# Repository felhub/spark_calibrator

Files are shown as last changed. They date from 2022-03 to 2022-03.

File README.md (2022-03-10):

# spark_calibrator
## Be carefull! Igntion coils can step up the voltage up to 1:100, wich means on the secondary side there can be voltages up to 40kV!
Over serial communication controlled spark generator using an arduino as digital controller and a car ignition coil as step up transformer.  
A 3D modell of the full assembly and spark gab, as well as all 3d printed parts will be added soon.

## Schematics (without Arduino)
A MOSFET is used to switch the coil. To avoid voltage spikes on the direct switching action, C2 is used to buffer the spike.  
To limit the overall voltage spike on the primary side, the TVS-diode D2 is used to limit to 440V.  

Switching and digital side are isolated via an optocoupler

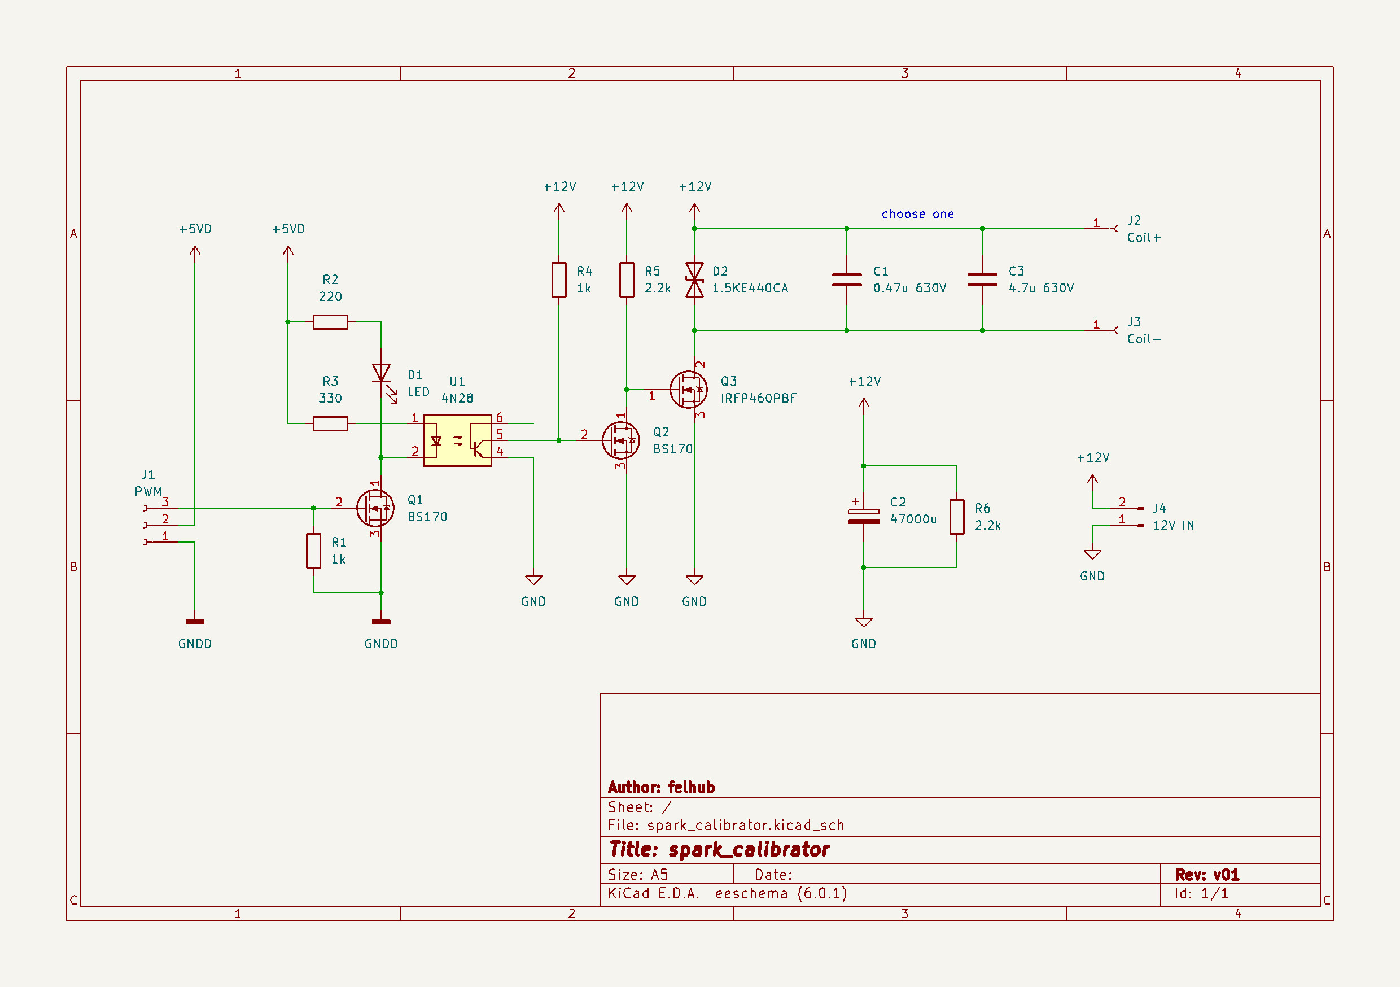
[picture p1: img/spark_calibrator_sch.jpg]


## Simulation

In blue one can see the input pwm signal, triggering the charge of the coil, seen in the current over the coil in red. After voltage to the coil is cut of, the magnetic field collapses with a huge voltage spike in green. The spike is limited by the TVS-diode to 440V, this can be seen as clipping on the green signal.

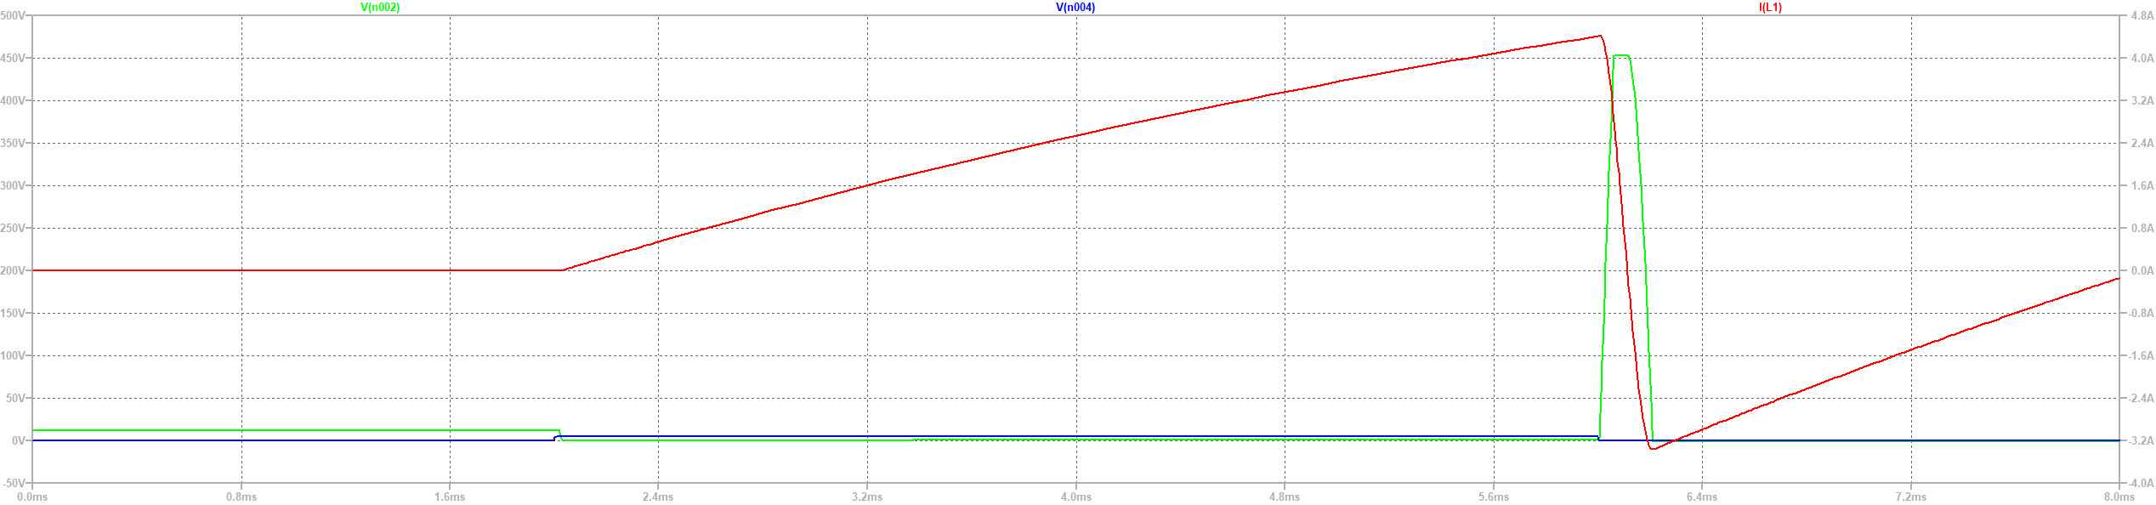
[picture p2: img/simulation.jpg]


## Board layout
The board can be screwed directly to the coil terminals, to keep the leads as short as possible, depending on your could the board has to be adjusted.  
The Arduino is mounted via a 3D printed part on the back of the coil and connects to the board via 3 wires.  

| main_board | ignition coil |
|:---:|:---:|
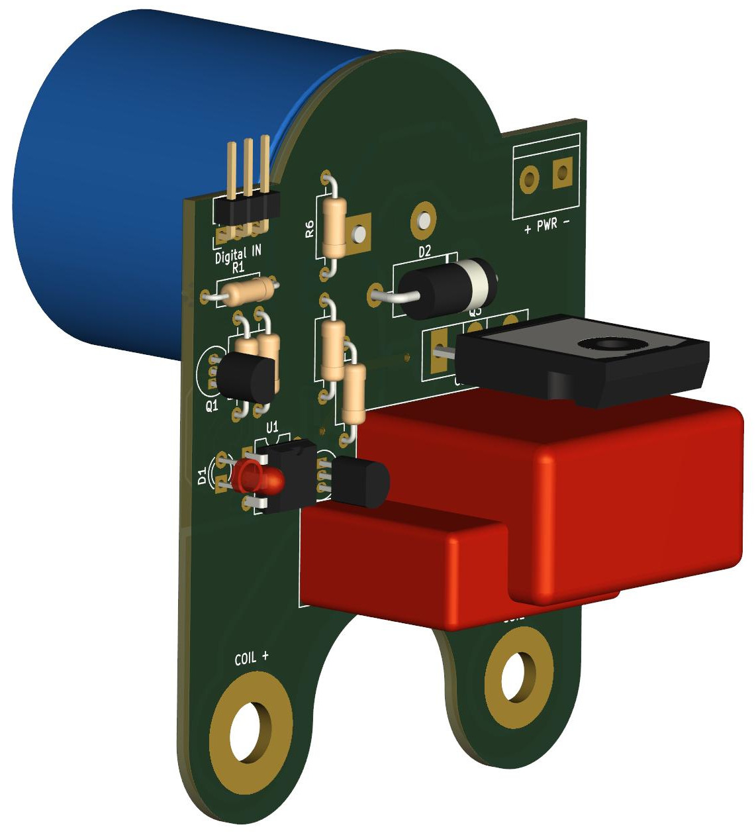
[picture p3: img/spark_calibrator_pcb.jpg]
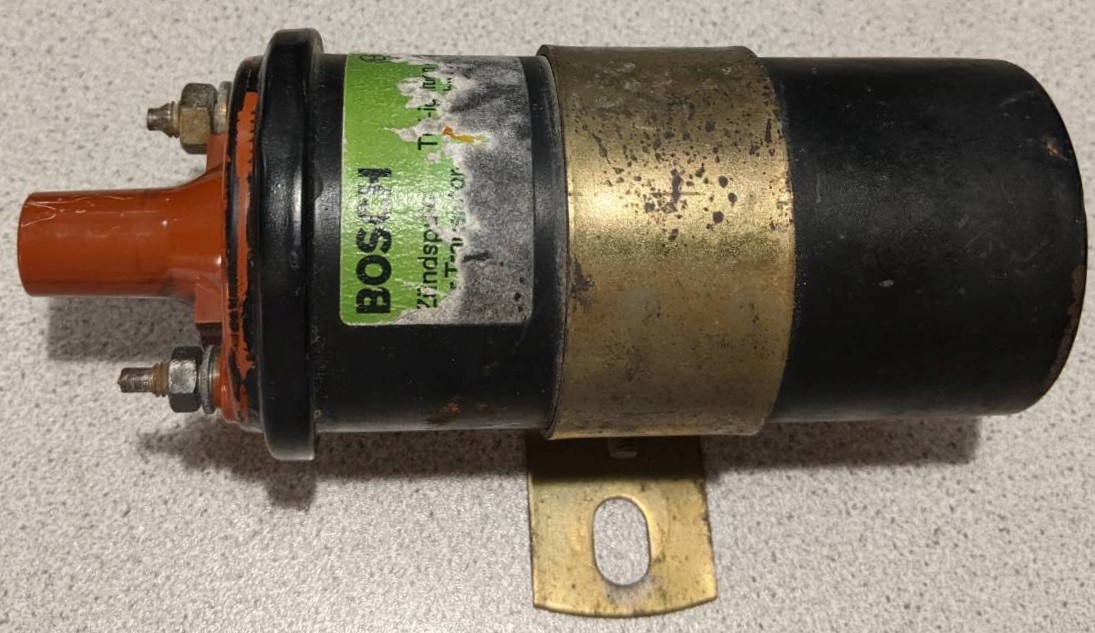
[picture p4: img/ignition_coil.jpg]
|  |  |

## Spark gap

In order to generate consistent sparks, the spark gap should consist of two pointy metal parts. For spark calibration, audio reflections should be avoided, therefore I build a small spark gap device, using sewing needles and cardboard. The width can be varied, to test the effect of the spark length on the generated impulse.

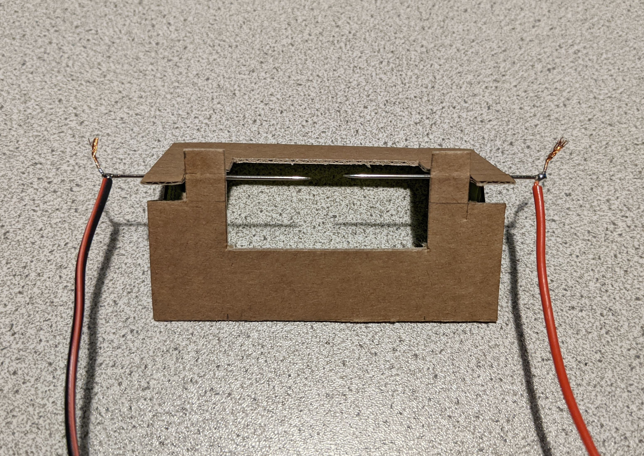
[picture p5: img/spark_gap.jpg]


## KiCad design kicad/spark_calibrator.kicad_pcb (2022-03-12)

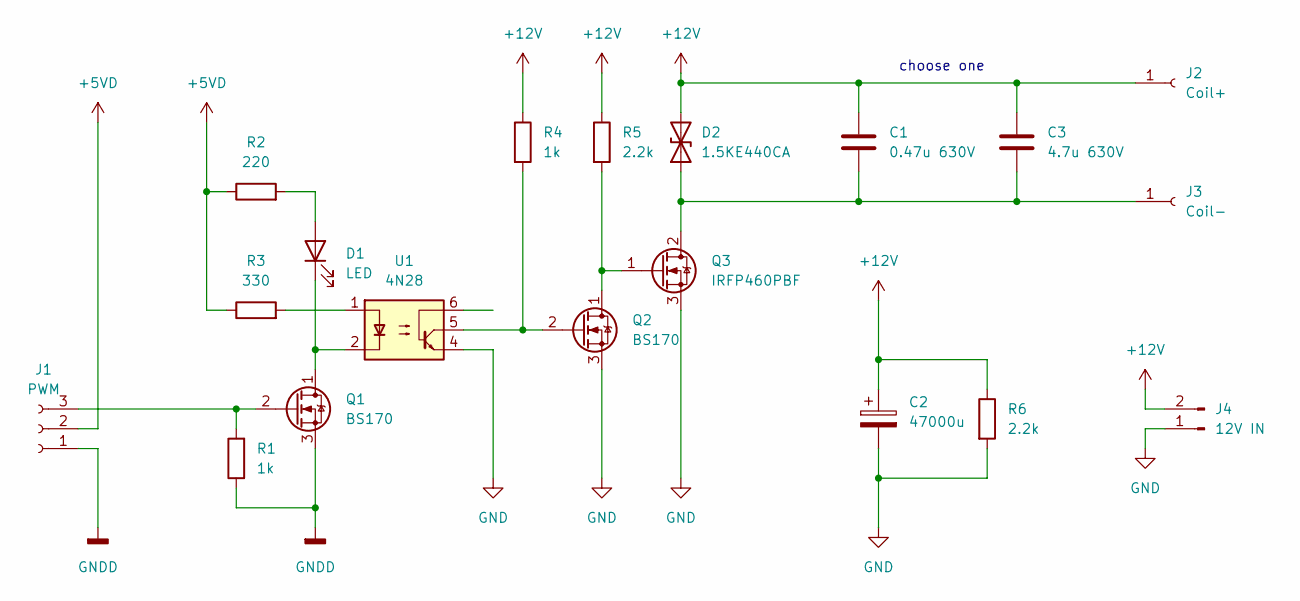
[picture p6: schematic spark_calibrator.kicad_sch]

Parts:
C1: 0.47u 630V; C_Rect_L26.5mm_W10.5mm_P22.50mm_MKS4
C2: 47000u; CP_Radial_D35.0mm_P10.00mm_SnapIn
C3: 4.7u 630V; C_Rect_L31.5mm_W17.0mm_P27.50mm_MKS4
D1: LED; LED_D3.0mm
D2: 1.5KE440CA; D_DO-201_P15.24mm_Horizontal
J1: PWM; PinHeader_1x03_P2.54mm_Horizontal
J2: Coil+; MountingHole_6.4mm_M6_Pad
J3: Coil-; MountingHole_5.3mm_M5_Pad
J4: 12V IN; TerminalBlock_bornier-2_P5.08mm
Q1, Q2: BS170; TO-92_Inline
Q3: IRFP460PBF; TO-247-3_Vertical
R1, R4: 1k; R_Axial_DIN0207_L6.3mm_D2.5mm_P10.16mm_Horizontal
R2: 220; R_Axial_DIN0207_L6.3mm_D2.5mm_P10.16mm_Horizontal
R3: 330; R_Axial_DIN0207_L6.3mm_D2.5mm_P10.16mm_Horizontal
R5, R6: 2.2k; R_Axial_DIN0207_L6.3mm_D2.5mm_P10.16mm_Horizontal
U1: 4N28; DIP-6_W7.62mm

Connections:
+5VD: J1.2, R2.1, R3.1
+12V: C1.1, C2.1, C3.1, D2.2 (A2), J2.1, J4.2, R4.1, R5.1, R6.1
GND: C2.2, J4.1, Q2.3 (S), Q3.3 (S), R6.2, U1.4
GNDD: J1.1, Q1.3 (S), R1.1
unnamed: C1.2, C3.2, D2.1 (A1), J3.1, Q3.2 (D)
unnamed: D1.1 (K), Q1.1 (D), U1.2
unnamed: D1.2 (A), R2.2
unnamed: J1.3, Q1.2 (G), R1.2
unnamed: Q2.1 (D), Q3.1 (G), R5.2
unnamed: Q2.2 (G), R4.2, U1.5
unnamed: R3.2, U1.1

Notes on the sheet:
choose one

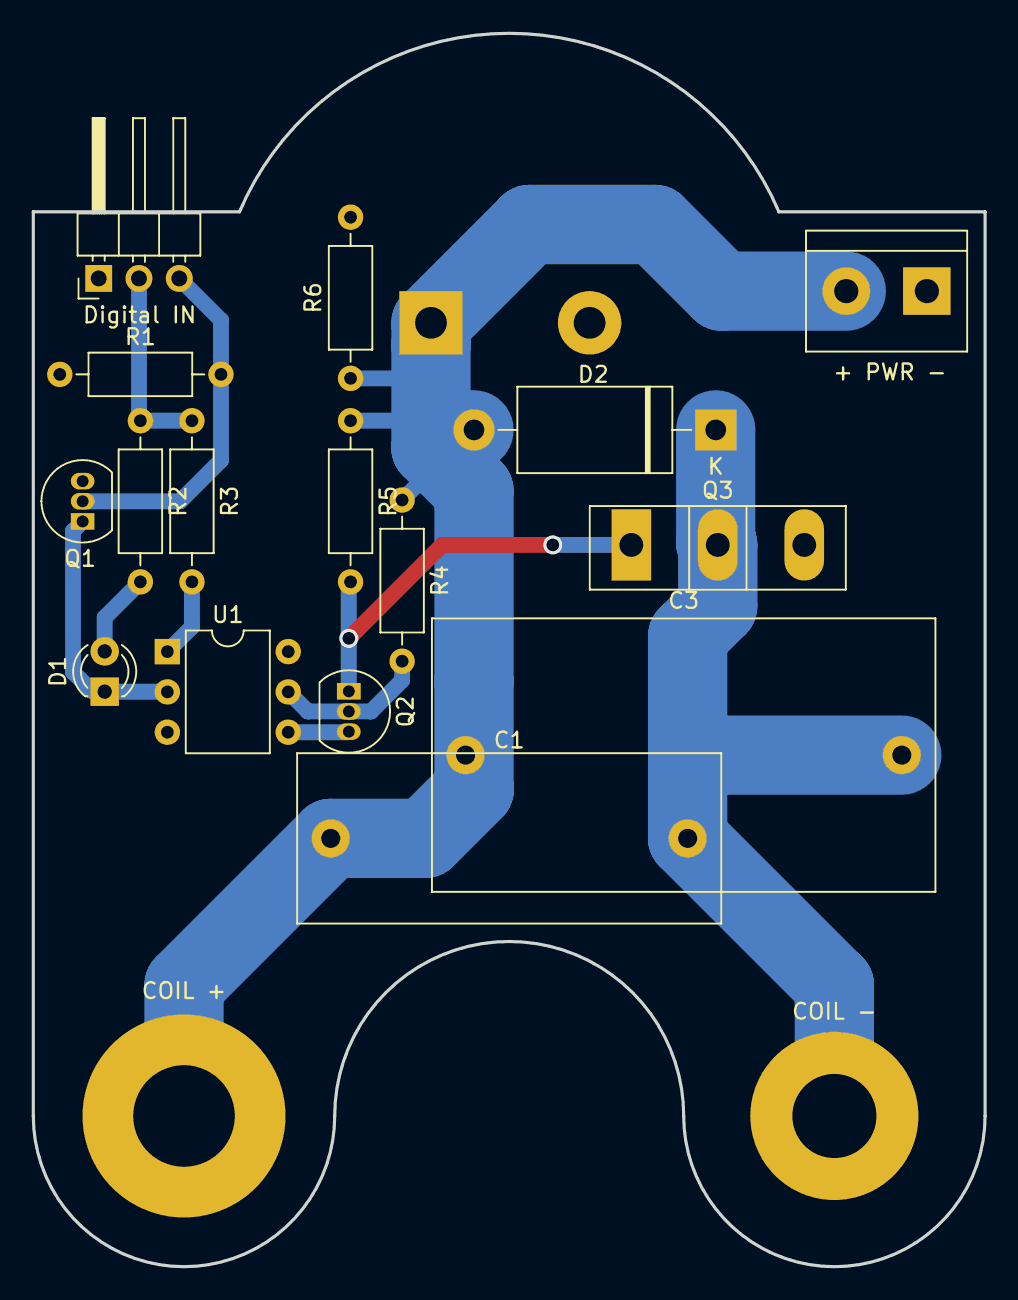
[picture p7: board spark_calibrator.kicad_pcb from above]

Board: 2 copper layers, 60.0 x 77.8 mm, 19 parts (1 on the bottom side), 11 nets.

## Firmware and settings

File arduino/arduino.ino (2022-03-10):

long onTime = 0;
int data;

#define outpin 2

void setup() {
  // initialize digital pin LED_BUILTIN as an output.
  pinMode(outpin, OUTPUT);
  digitalWrite(outpin, LOW);

  Serial.begin(115200);
  Serial.setTimeout(1);
}

// the loop function runs over and over again forever
void loop() {
  if(Serial.available() > 0){
    data = Serial.read();
    if(data == 'F'){
      onTime = millis();
      digitalWrite(outpin, HIGH);
    }
  }

  if(millis()-onTime > 10 && digitalRead(outpin)){
    digitalWrite(outpin, LOW);
    Serial.println("done");
  }
}

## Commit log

2022-03-07 aestetic updates
    [spark_calibrator.kicad_pcb, spark_calibrator.kicad_sch]
2022-03-07 added arduino code
2022-03-10 faster off switching
    [spark_calibrator.kicad_pcb, spark_calibrator.kicad_sch]
2022-03-12 first prototype
    [spark_calibrator.kicad_pcb]
2022-03-14 R4 to 2.2k
    [spark_calibrator.kicad_sch]
